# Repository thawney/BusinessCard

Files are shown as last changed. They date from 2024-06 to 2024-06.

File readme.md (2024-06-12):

# Thawney's Ultimate Business Card Of Businessynes

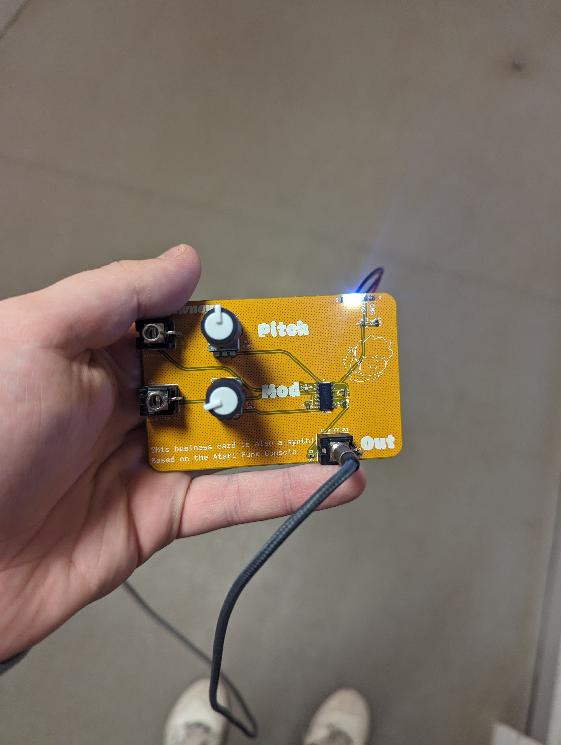
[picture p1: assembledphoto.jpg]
Picture of assembled card


Ello! Thawney here :D this is my business card. It is a very simple design based on the atari punk console that gives the user a pitch and modulation knob and control voltage input and can be powered from a 9v battery.

It is recommended to use alpha 9mm potentiometer but any will do! The audio/cv in jacks are thonkicon (WQP518MA). If you are Bristol based then come and visit Bristol Communal Modular on a Tuesday, they might have some spares.

!!NOTE!! If you are one of the lovely people who came to my Dorkbot Bristol talk on 11/06/2024 then the business cards I gave you have the potentiometers wired backwards for pitch and modulation, I'm sorry D:

# Hacking the Card

There are a lot of fun hacks you can do! For example, the potentiometers are wired as variable resistors which means you can replace them with fun resistors (Like LDRs or Thermistors) and control the card in new fun ways.

To do this just ensure that you are placing the legs of your components in pins that ARE NOT already connected with the components!

If you want to do something less technical, try heating up or cooling the chip on the circuit board to mess with the tuning!

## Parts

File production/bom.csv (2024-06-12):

Designator | Footprint | Quantity | Value | LCSC Part #
C1, C4 | 0603 | 2 | 0.1uF
C2, C5 | 0603 | 2 | 10uf
C3 | 0603 | 1 | 0.01uF
D1 | 0603 | 1 | LED
FID1, FID2, FID3 | Fiducial_1mm_Mask2mm | 3 | Fiducial_1mm_Mask2mm
J1 | PinSocket_1x02_P2.54mm_Vertical | 1 | Socket_01x02
J2 | EighthInch_PJ398SM | 1 | MODULATION CV
J3 | EighthInch_PJ398SM | 1 | PITCH CV
J4 | EighthInch_PJ398SM | 1 | AUDIO OUT
R1, R2 | 0603 | 2 | 1k
R3 | 0603 | 1 | 10k
R4 | 0603 | 1 | 4.7k
RV1, RV2 | Pot_9mm_DShaft | 2 | 500k
U1 | SOIC-14_3.9x8.7mm_P1.27mm | 1 | LM556

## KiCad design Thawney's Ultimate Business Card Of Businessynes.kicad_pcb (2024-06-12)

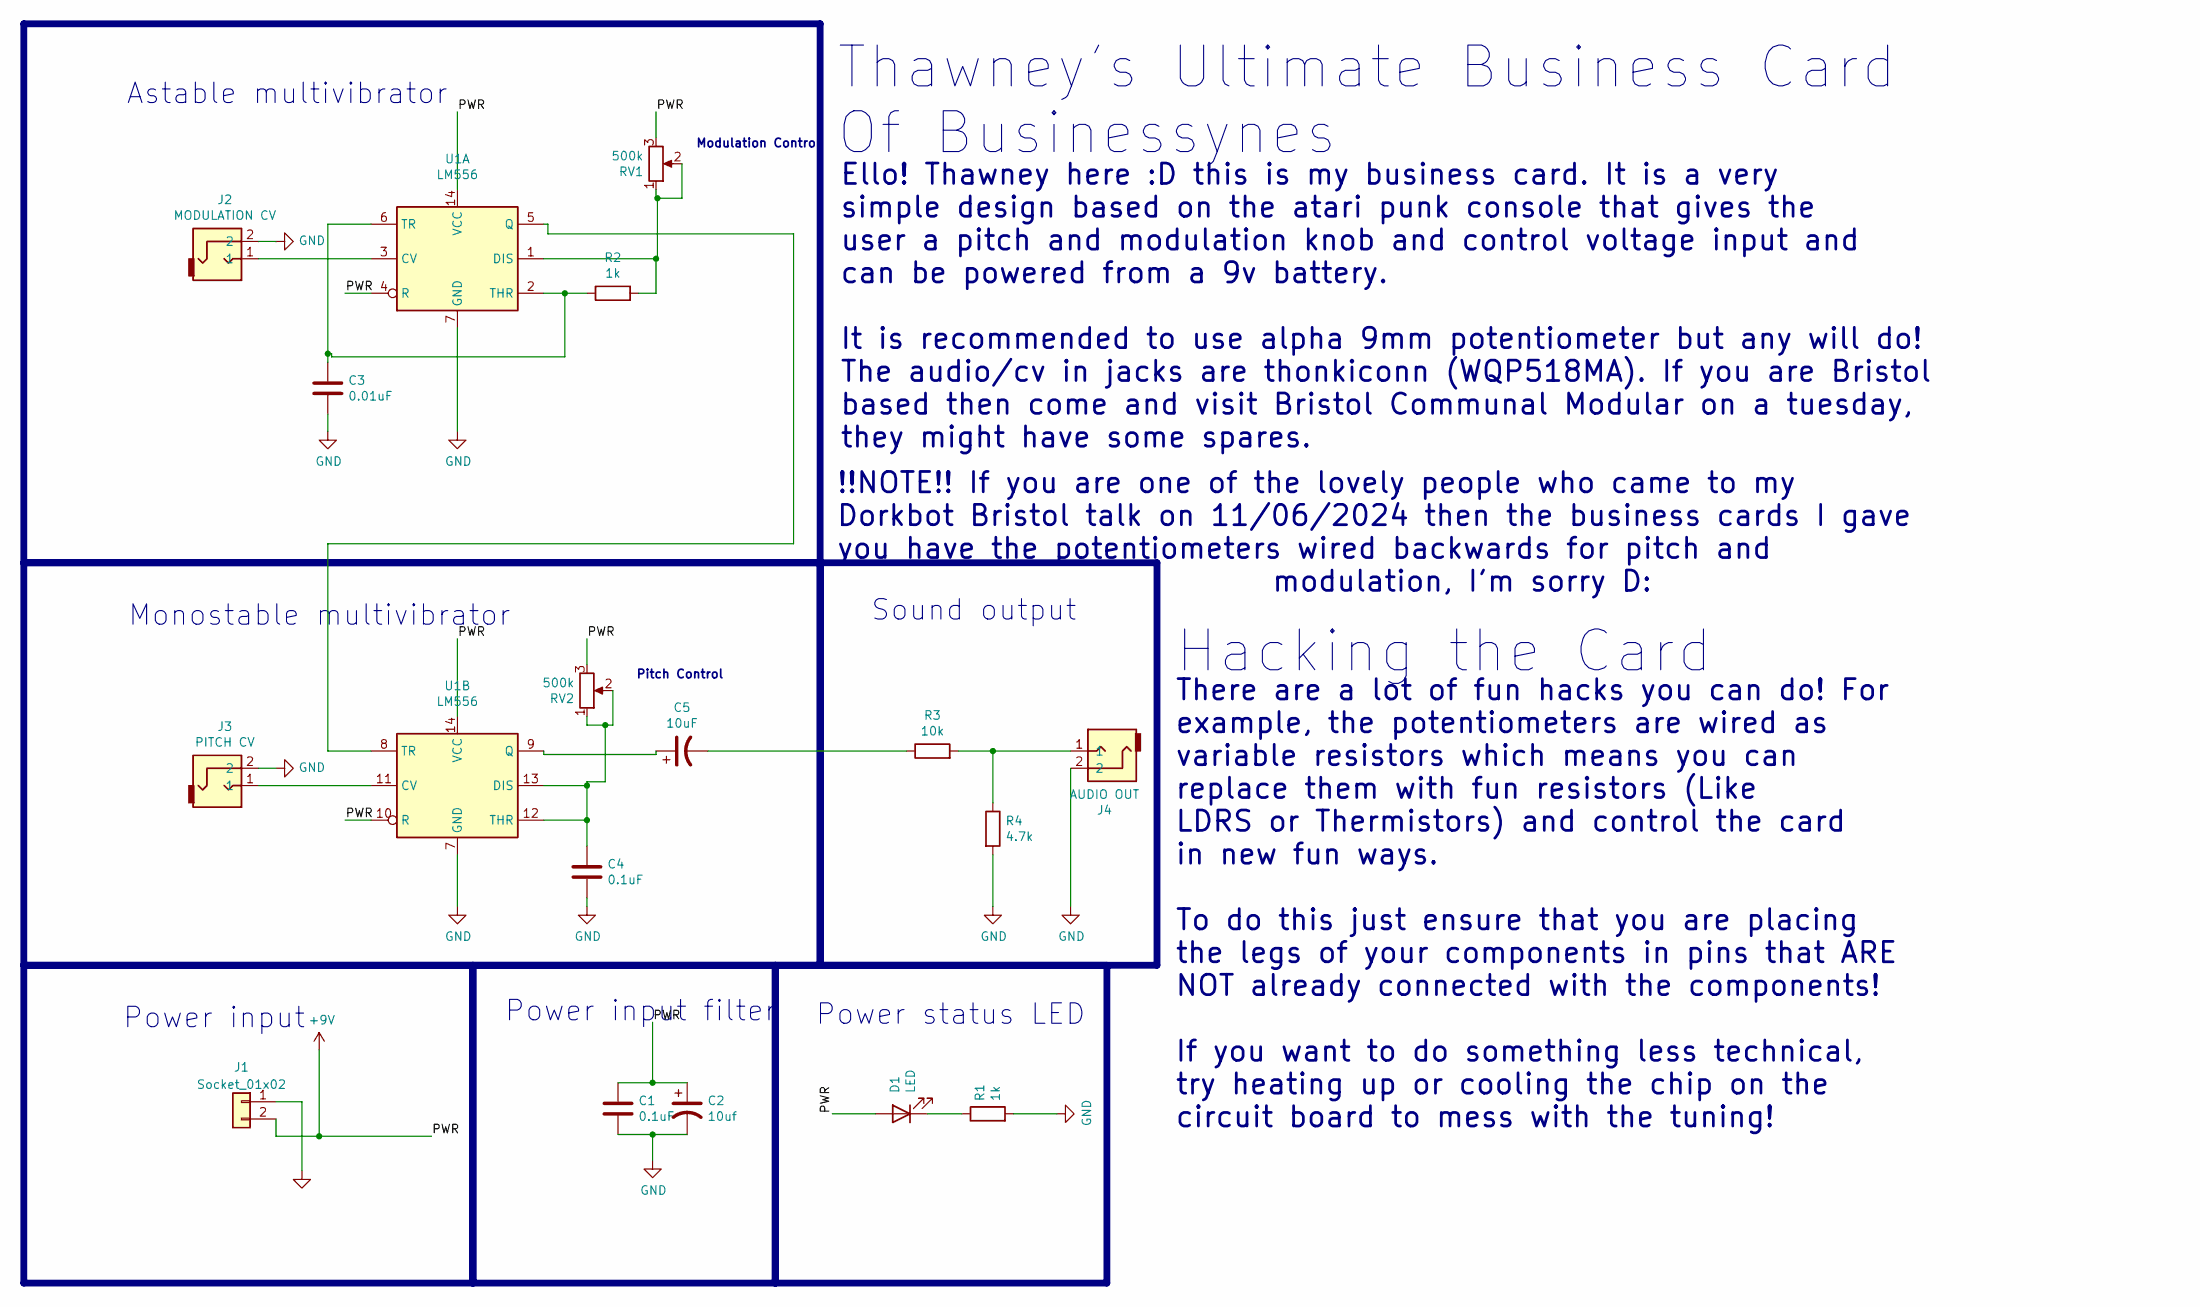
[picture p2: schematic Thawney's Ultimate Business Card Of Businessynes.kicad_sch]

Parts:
C1, C4: 0.1uF; C_0603_1608Metric
C2: 10uf; C_0603_1608Metric
C3: 0.01uF; C_0603_1608Metric
C5: 10uF; C_0603_1608Metric
D1: LED; LED_0603_1608Metric
J1: Socket_01x02; PinSocket_1x02_P2.54mm_Vertical; Part Number ?
J2: MODULATION CV; EighthInch_PJ398SM
J3: PITCH CV; EighthInch_PJ398SM
J4: AUDIO OUT; EighthInch_PJ398SM
R1, R2: 1k; R_0603_1608Metric
R3: 10k; R_0603_1608Metric
R4: 4.7k; R_0603_1608Metric
RV1, RV2: 500k; Pot_9mm_DShaft
U1: LM556; SOIC-14_3.9x8.7mm_P1.27mm

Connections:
+9V: C1.1, C2.1, D1.2 (A), J1.2, RV1.3, RV2.3, U1.4 (R), U1.10 (R), U1.14 (VCC)
GND: C1.2, C2.2, C3.2, C4.2, J1.1, J2.2, J3.2, J4.2, R1.2, R4.2, U1.7 (GND)
unnamed: C5.2, R3.1
unnamed: D1.1 (K), R1.1
unnamed: J4.1, R3.2, R4.1
unnamed: J2.1, U1.3 (CV)
unnamed: R2.2, RV1.1, RV1.2, U1.1 (DIS)
unnamed: U1.5 (Q), U1.8 (TR)
unnamed: C3.1, R2.1, U1.2 (THR), U1.6 (TR)
unnamed: J3.1, U1.11 (CV)
unnamed: C4.1, RV2.1, RV2.2, U1.12 (THR), U1.13 (DIS)
unnamed: C5.1, U1.9 (Q)

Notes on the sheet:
Thawney's Ultimate Business Card Of Businessynes
Ello! Thawney here :D this is my business card. It is a very simple design based on the atari punk console that gives the user a pitch and modulation knob and control voltage input and can be powered from a 9v battery. It is recommended to use alpha 9mm potentiometer but any will do! The audio/cv i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
There are a lot of fun hacks you can do! For example, the potentiometers are wired as variable resistors which means you can replace them with fun resistors (Like LDRS or Thermistors) and control the card in new fun ways. To do this just ensure that you are placing the legs of your components in pi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
Sound output
Power status LED
Power input
Hacking the Card
Monostable multivibrator
!!NOTE!! If you are one of the lovely people who came to my Dorkbot Bristol talk on 11/06/2024 then the business cards I gave you have the potentiometers wired backwards for pitch and modulation, I'm sorry D:
Pitch Control
Astable multivibrator
Power input filter
Modulation Control

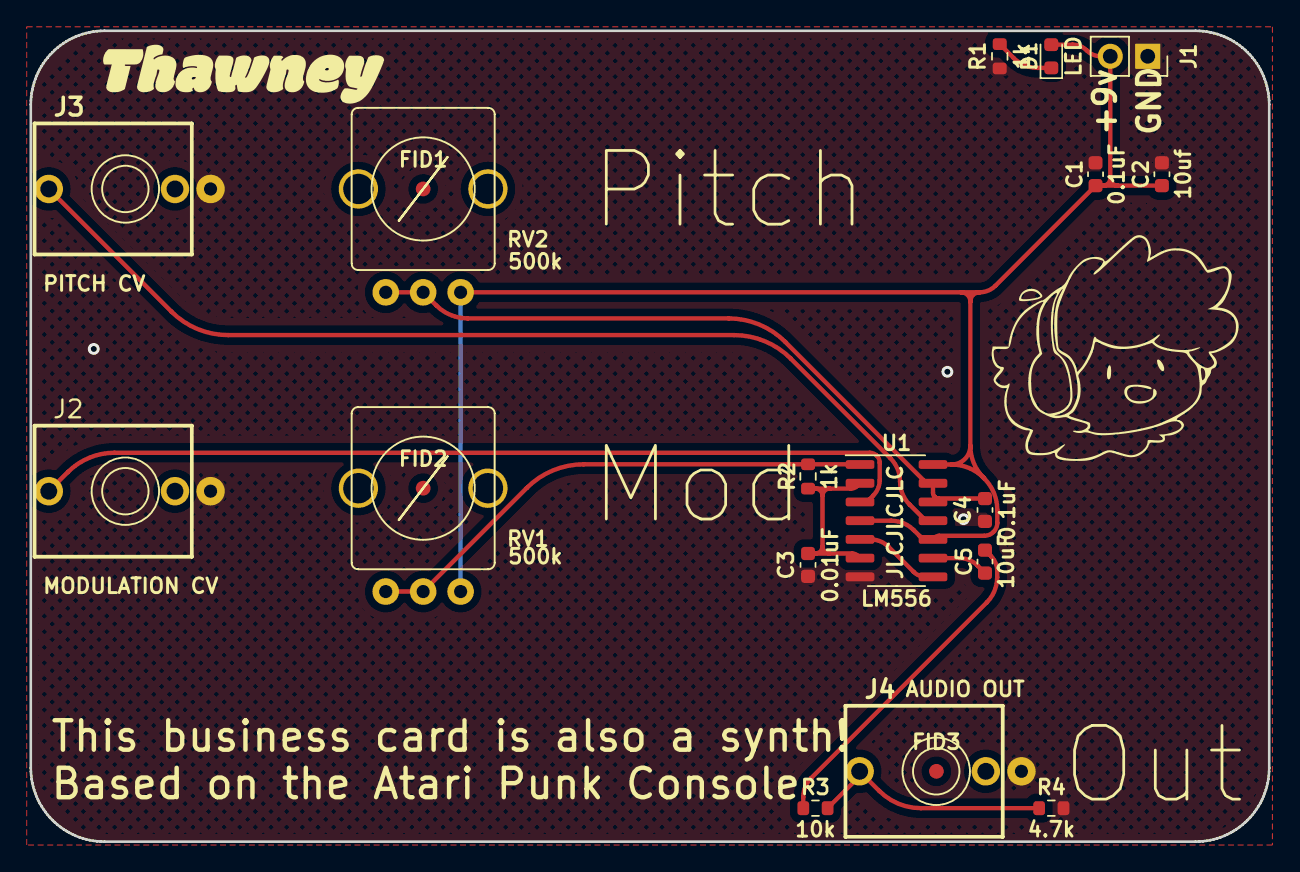
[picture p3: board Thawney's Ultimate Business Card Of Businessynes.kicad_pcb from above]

Board: 2 copper layers, 84.0 x 55.0 mm, 20 parts (0 on the bottom side), 12 nets.

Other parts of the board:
FID1, FID2, FID3: Fiducial_1mm_Mask2mm
